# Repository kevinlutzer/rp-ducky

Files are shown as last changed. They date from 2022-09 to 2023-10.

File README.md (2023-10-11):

# RP Ducky

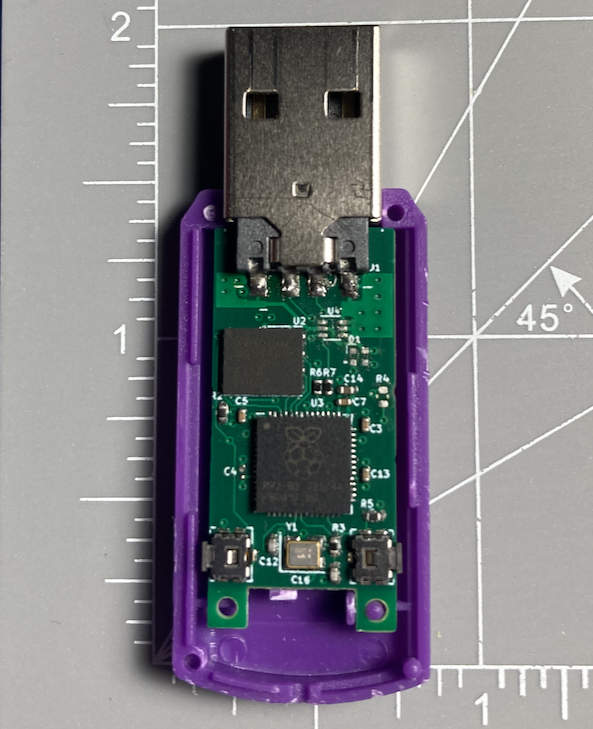
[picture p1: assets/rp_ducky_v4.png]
V4 PCB


A RP2040 based keystroke injector that uses standard [Ducky Script](https://docs.hak5.org/hak5-usb-rubber-ducky/duckyscript-tm-quick-reference). Unlike the original Rubber Ducky from Hak5, this module does not require the scripts to be loaded over an SD card. Instead, you can start the RP Ducky in USB Storage mode to both update the code and the scripts on the device.

## Fabrication

The PCBs are fabricated as a 4 layer board with JLCPCBs JLC04161H-7628A stackup. The bill of materials and the gerber files are available in the [fab](./fab) folder. The USB covering the PCB is designed for can be found on [Alibaba](https://www.alibaba.com/product-detail/Custom-Logo-2-0-3-0_1600456187162.html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) or on [Amazon](https://www.amazon.ca/RAOYI-Drives-Memory-Storage-Swivel/dp/B07KS1TTCH?ref_=ast_slp_dp&th=1) 

## Usage

To upload the code and scripts to the RP Ducky, you need to put the RP Ducky into USB Storage mode. To do this, hold the button `BOOT` and `RESET` buttons down while plugging the device into a computer. Release the `BOOT` button first and then the `RESET` button. The device will show up as storage device. Copy Adafruit's [Raspberry Pi Pico UF2 Circuit Python file](https://circuitpython.org/board/raspberry_pi_pico/) on to the RP Ducky. You can then copy the contents of [code](./code/) onto the device. To run the test script, copy `sample/payloads/rickroll_macos.txt` to the RP Ducky's root directory and rename it to `payload.txt`

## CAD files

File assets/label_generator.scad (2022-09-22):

/*
    Creates labels for the diode ring modulator pcb

    Author: Kevin Lutzer
    Date: Sat Sept 10 2022
*/

// generates a rounded box with some text in the center



module generateLabel(width, height, radius, label, ts) {
    $fn=40;

    difference() {
        translate([- width / 2, - height / 2]) {
            minkowski() {
              square([width, height]);
              circle(r=radius);
            }
        }

        text(label, font="Liberation Sans:style=Bold", valign="center", halign="center", size=ts);        
    }       
}

// Each label was made with the dimensions of 4mm by 2.666mm 
//generateLabel(4.5, 2, 0.25, "RST", 1.5); 
//generateLabel(6, 2, 0.25, "BOOT", 1.5); 

generateLabel(5, 2, 0.25, "Rev3", 1.5); 

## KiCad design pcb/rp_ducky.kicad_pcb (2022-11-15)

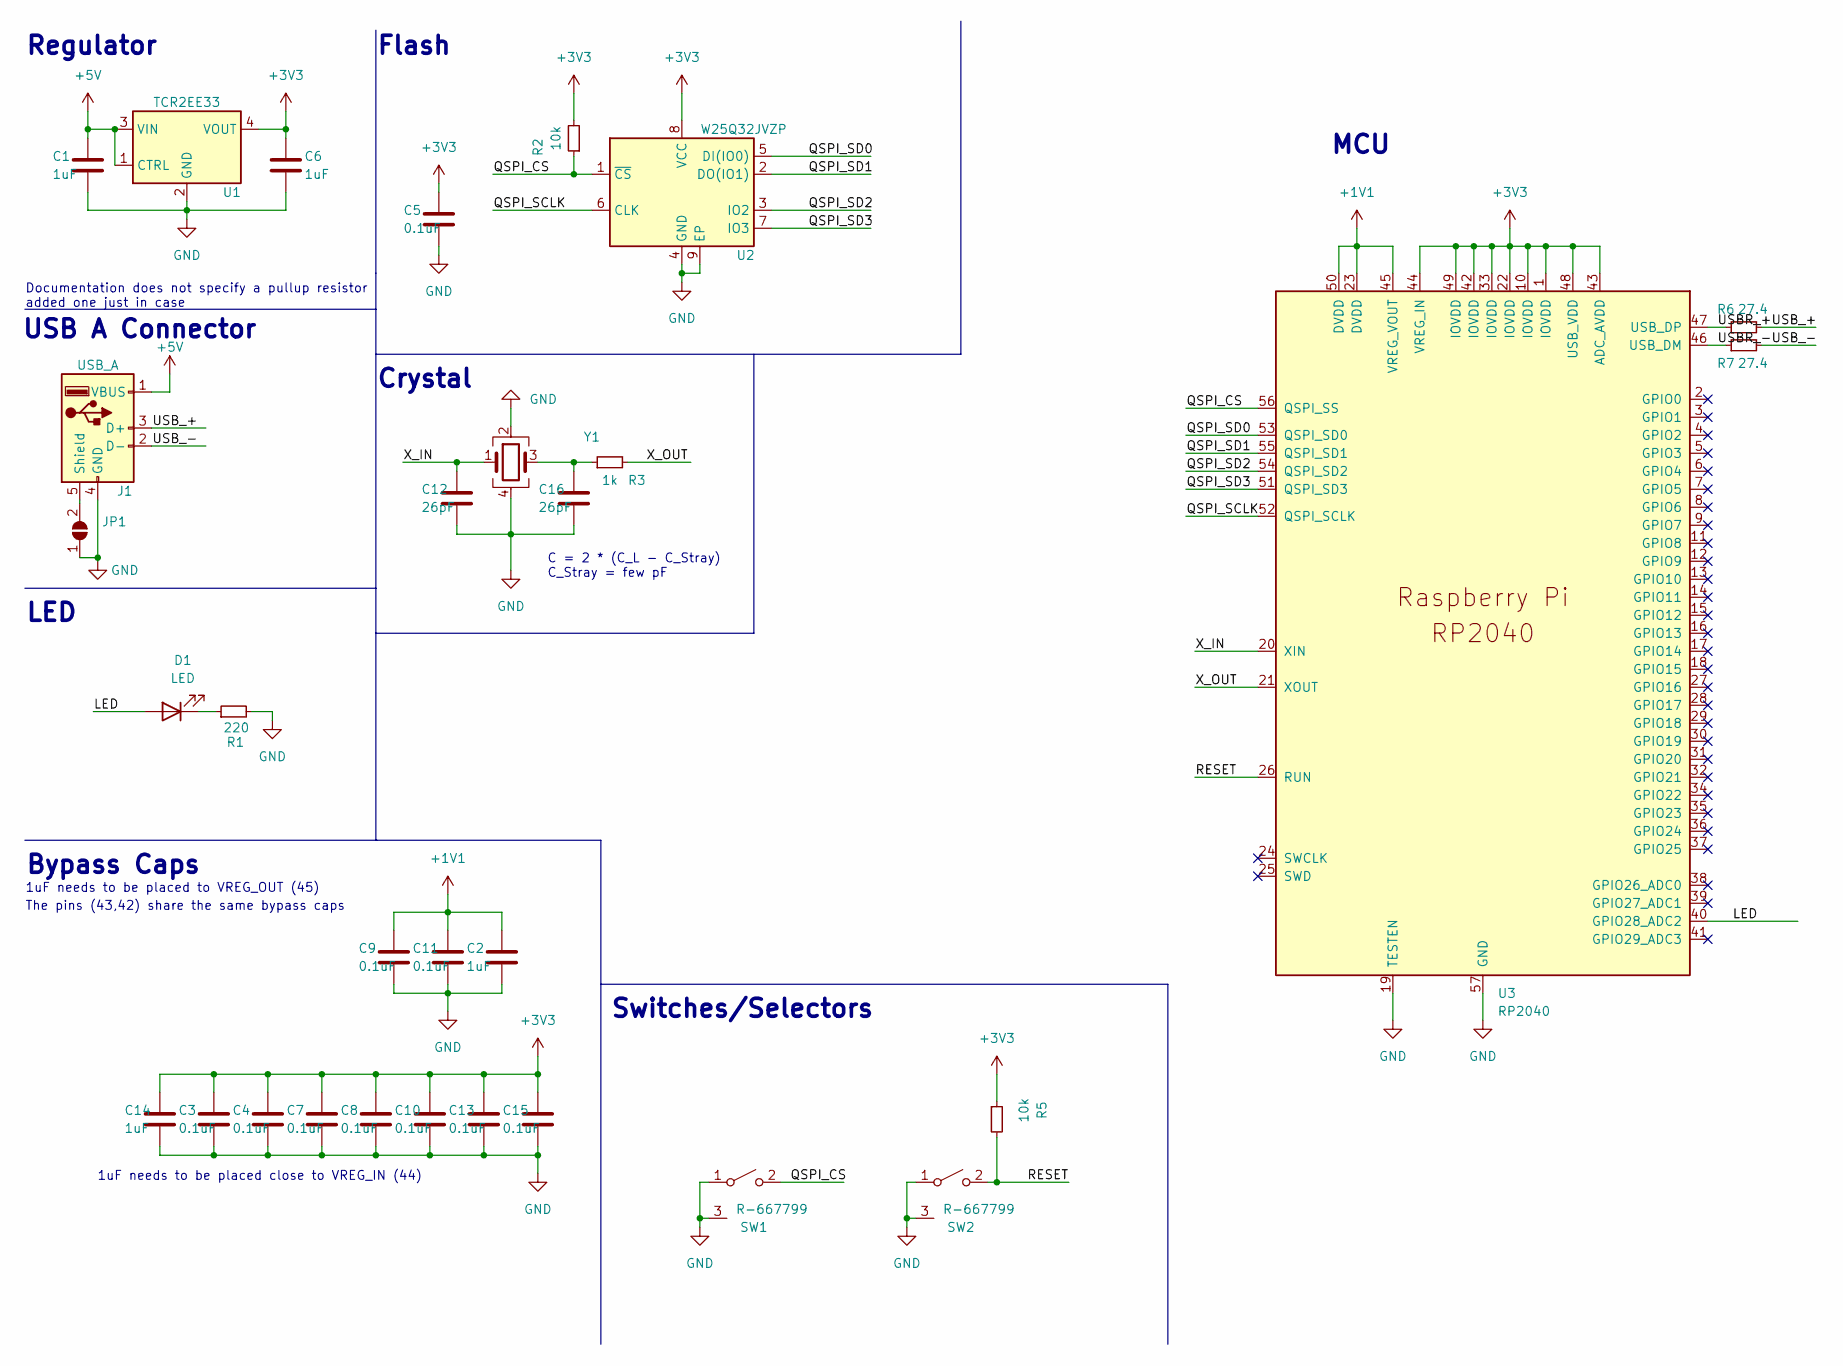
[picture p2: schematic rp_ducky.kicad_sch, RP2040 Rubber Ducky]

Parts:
C1, C2, C6, C14: 1uF; C_0402_1005Metric
C3, C4, C5, C7, C8, C9, C10, C11, C13, C15: 0.1uF; C_0201_0603Metric
C12, C16: 26pF; C_0402_1005Metric
D1: LED; LED_0603_1608Metric
J1: USB_A; USB3_A_Plug_Wuerth_629004113921_Horizontal
JP1: SolderJumper_2_Open; SolderJumper-2_P1.3mm_Open_TrianglePad1.0x1.5mm
R1: 220; R_0402_1005Metric
R2, R5: 10k; R_0402_1005Metric
R3: 1k; R_0402_1005Metric
R6, R7: 27.4; R_0201_0603Metric
SW1, SW2: R-667799
U1: TCR2EE33; SOT-553
U2: W25Q32JVZP; WSON-8-1EP_6x5mm_P1.27mm_EP3.4x4.3mm
U3: RP2040; RP2040-QFN-56
Y1: Crystal_GND24; Crystal_SMD_2520-4Pin_2.5x2.0mm

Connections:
+1V1: C2.2, C9.2, C11.2, U3.23 (DVDD), U3.45 (VREG_VOUT), U3.50 (DVDD)
+3V3: C3.2, C4.2, C5.2, C6.2, C7.2, C8.2, C10.2, C13.2, C14.2, C15.2, R2.2, R5.1, U1.4 (VOUT), U2.8 (VCC), U3.1 (IOVDD), U3.10 (IOVDD), U3.22 (IOVDD), U3.33 (IOVDD), U3.42 (IOVDD), U3.43 (ADC_AVDD), U3.44 (VREG_IN), U3.48 (USB_VDD), U3.49 (IOVDD)
+5V: C1.2, J1.1 (VBUS), U1.1 (CTRL), U1.3 (VIN)
/LED: D1.2 (A), U3.40 (GPIO28_ADC2)
/QSPI_CS: R2.1, SW1.2 (B), U2.1 (~CS), U3.56 (QSPI_SS)
/QSPI_SCLK: U2.6 (CLK), U3.52 (QSPI_SCLK)
/QSPI_SD0: U2.5 (DI(IO0)), U3.53 (QSPI_SD0)
/QSPI_SD1: U2.2 (DO(IO1)), U3.55 (QSPI_SD1)
/QSPI_SD2: U2.3 (IO2), U3.54 (QSPI_SD2)
/QSPI_SD3: U2.7 (IO3), U3.51 (QSPI_SD3)
/RESET: R5.2, SW2.2 (B), U3.26 (RUN)
/USBR_+: R6.1, U3.47 (USB_DP)
/USBR_-: R7.1, U3.46 (USB_DM)
/USB_+: J1.3 (D+), R6.2
/USB_-: J1.2 (D-), R7.2
/X_IN: C12.2, U3.20 (XIN), Y1.1
/X_OUT: R3.2, U3.21 (XOUT)
GND: C1.1, C2.1, C3.1, C4.1, C5.1, C6.1, C7.1, C8.1, C9.1, C10.1, C11.1, C12.1, C13.1, C14.1, C15.1, C16.1, J1.4 (GND), JP1.1 (A), R1.2, SW1.1 (A), SW1.3 (SH), SW2.1 (A), SW2.3 (SH), U1.2 (GND), U2.4 (GND), U2.9 (EP), U3.19 (TESTEN), U3.57 (GND), Y1.2, Y1.4
unnamed: C16.2, R3.1, Y1.3
unnamed: D1.1 (K), R1.1
unnamed: J1.5 (Shield), JP1.2 (B)

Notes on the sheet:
Bypass Caps
Switches/Selectors
Crystal
C = 2 * (C_L - C_Stray) C_Stray = few pF
1uF needs to be placed to VREG_OUT (45)
Regulator
1uF needs to be placed close to VREG_IN (44)
Documentation does not specify a pullup resistor added one just in case
The pins (43,42) share the same bypass caps
Flash
USB A Connector
LED
MCU

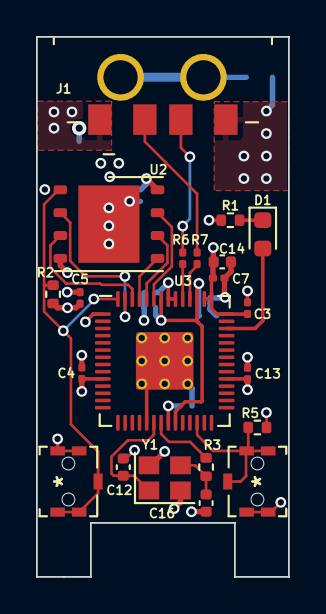
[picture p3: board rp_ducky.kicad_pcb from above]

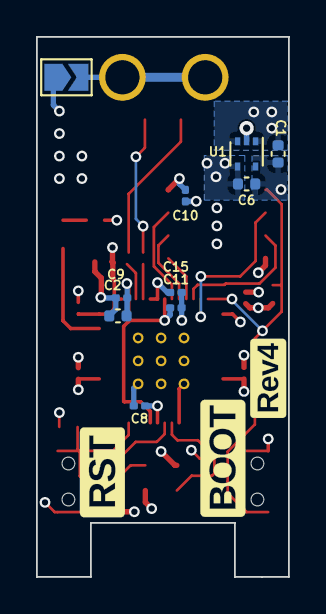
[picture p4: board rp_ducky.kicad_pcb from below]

Board: 4 copper layers, 14.0 x 30.0 mm, 31 parts (10 on the bottom side), 21 nets.

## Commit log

2022-04-26 build out most of the schematic, currently working on crystal, what one to use?
    [pico_ducky_pcb.kicad_pcb, pico_ducky_pcb.kicad_sch]
2022-04-30 get the placement 90% switch out SW1 and SW2 to buttons that are 1mm thick
    [pico_ducky_pcb.kicad_pcb, pico_ducky_pcb.kicad_sch]
2022-05-01 finish most of the inpours, routing and vias
    [pico_ducky_pcb.kicad_pcb, pico_ducky_pcb.kicad_sch]
2022-05-02 git ignore
    [pico_ducky_pcb.kicad_pcb]
2022-05-03 pass erc
    [pico_ducky_pcb.kicad_pcb, pico_ducky_pcb.kicad_sch]
2022-05-03 finish the layout
    [pico_ducky_pcb.kicad_pcb, pico_ducky_pcb.kicad_sch]
2022-05-03 add bom
    [pico_ducky_pcb.csv]
2022-05-04 fix silk screen adnd use 10 pin JTAG programmer
    [pico_ducky_pcb.kicad_pcb, pico_ducky_pcb.kicad_sch]
2022-05-04 add pcbs for prints
2022-05-05 add the v1 gerber zips
2022-05-25 add v2
    [pico_ducky_pcb.csv, pico_ducky_pcb.kicad_pcb, pico_ducky_pcb.kicad_sch]
2022-05-25 start stripping v1 features
    [pico_ducky_pcb.kicad_sch]
2022-06-02 route out most of the pcb
    [pico_ducky_pcb.kicad_pcb, pico_ducky_pcb.kicad_sch]
2022-06-03 fix issues with mic5504mt compoennt
    [pico_ducky_pcb.kicad_pcb]
2022-06-04 finish routing neopizel
    [pico_ducky_pcb.kicad_pcb, pico_ducky_pcb.kicad_sch]
2022-06-04 remove backup files remove print files remove gerbbers from v2, move v1 fab files to the v1 section
    [pico_ducky_pcb.csv]
2022-06-04 add the v1 gerbers
2022-06-04 just leave the project behind in the v1 folder
    [pico_ducky_pcb-B_Cu.gbl, pico_ducky_pcb-B_Mask.gbs, pico_ducky_pcb-B_Paste.gbp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]
2022-06-04 move pcb files
    [pico_ducky_pcb.kicad_pcb, pico_ducky_pcb.kicad_sch]
2022-06-04 move bom file
2022-06-04 add local rp2040, mic5504 symbols and footprints
    [pico_ducky_pcb.kicad_sch]
2022-06-04 update R-667799 kicad footprint
    [pico_ducky_pcb.kicad_sch]
2022-06-05 update the R-667799 footprint and component finish routing
    [pico_ducky_pcb.kicad_pcb, pico_ducky_pcb.kicad_sch]
2022-06-06 add silk screen
    [pico_ducky_pcb.kicad_pcb, pico_ducky_pcb.kicad_sch]
2022-06-07 pico duck
    [pico_ducky_pcb.kicad_pcb]
2022-06-08 more silkscreen cleanup{
    [pico_ducky_pcb.kicad_pcb]
2022-06-10 use the weurth usb a connector
    [pico_ducky_pcb.kicad_pcb, pico_ducky_pcb.kicad_sch]
2022-06-15 add v2 gerber fab files
    [pico_ducky_pcb-B_Cu.gbl, pico_ducky_pcb-B_Mask.gbs, pico_ducky_pcb-B_Paste.gbp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]
2022-07-07 add the v2 bom
2022-09-22 add the v3 files
    [label_generator.scad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]
2022-09-22 move some of the files around deleted the v2 pcb stuff
    [pico_ducky_pcb.kicad_pcb, pico_ducky_pcb.kicad_sch, rp_ducky.kicad_pcb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]
2022-09-22 fix the rp ducky stuff
    [rp_ducky.kicad_pcb, rp_ducky.kicad_sch]
2022-10-08 add some code that works for the prototype
2022-10-19 remove level shifter for the SK8012 rgb led
    [rp_ducky.kicad_pcb, rp_ducky.kicad_sch]
2022-10-19 add rev4 label and update the pcb to use it
    [rp_ducky.kicad_pcb]
2022-11-02 add v4 gerbers
    [rp_ducky-B_Cu.gbl, rp_ducky-B_Mask.gbs, rp_ducky-B_Paste.gbp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]
2022-11-15 update the ibom and gerbers
    [rp_ducky-B_Cu.gbl, rp_ducky-B_Mask.gbs, rp_ducky-B_Paste.gbp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]
